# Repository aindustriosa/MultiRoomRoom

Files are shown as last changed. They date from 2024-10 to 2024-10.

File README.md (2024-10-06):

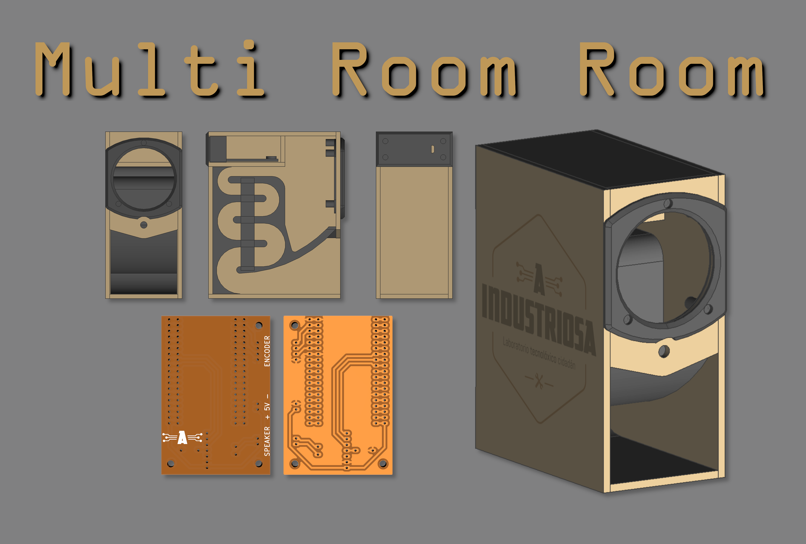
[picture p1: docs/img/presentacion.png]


Multi Room Room é un sistema de audio inalámbrico multi-habitación baseado en ESP32, Squeezelite[(1)](#1-httpsgithubcomsle118squeezelite-esp32) e Lyrion[(2)](#2-httpsgithubcomlms-communityslimserver). Permite a implementación dun sistema de fío musical inalámbrico de baixo custo e con tecnoloxías abertas. Neste repositorio atópanse as listas de materiais, deseños de placas electrónicas e caixas así como as instruccións para a posta en marcha do sistema.

## Documentación

[Documentación en galego](./docs/gl/INDICE.md)

Documentation in English (In progress)

## Referencias

#### [(1) https://github.com/sle118/squeezelite-esp32](https://github.com/sle118/squeezelite-esp32)

#### [(2) https://github.com/lms-community/slimserver](https://github.com/lms-community/slimserver)

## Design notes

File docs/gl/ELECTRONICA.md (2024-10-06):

# ESP32 + MAX98357A

Esta é a placa máis sinxela que permite implementar un altofalante dunha única canle (mono) e unha única vía (só un woofer). É a opción máis barata e compacta polo que é ideal se se queren fabricar múltiples unidades para cubrir unha estancia grande.

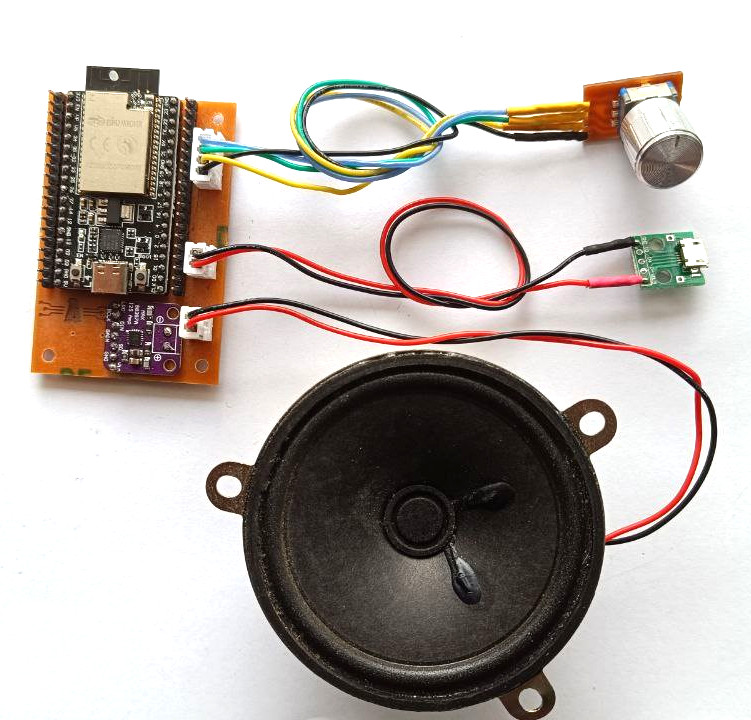
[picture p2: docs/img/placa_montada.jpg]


# Esquemático

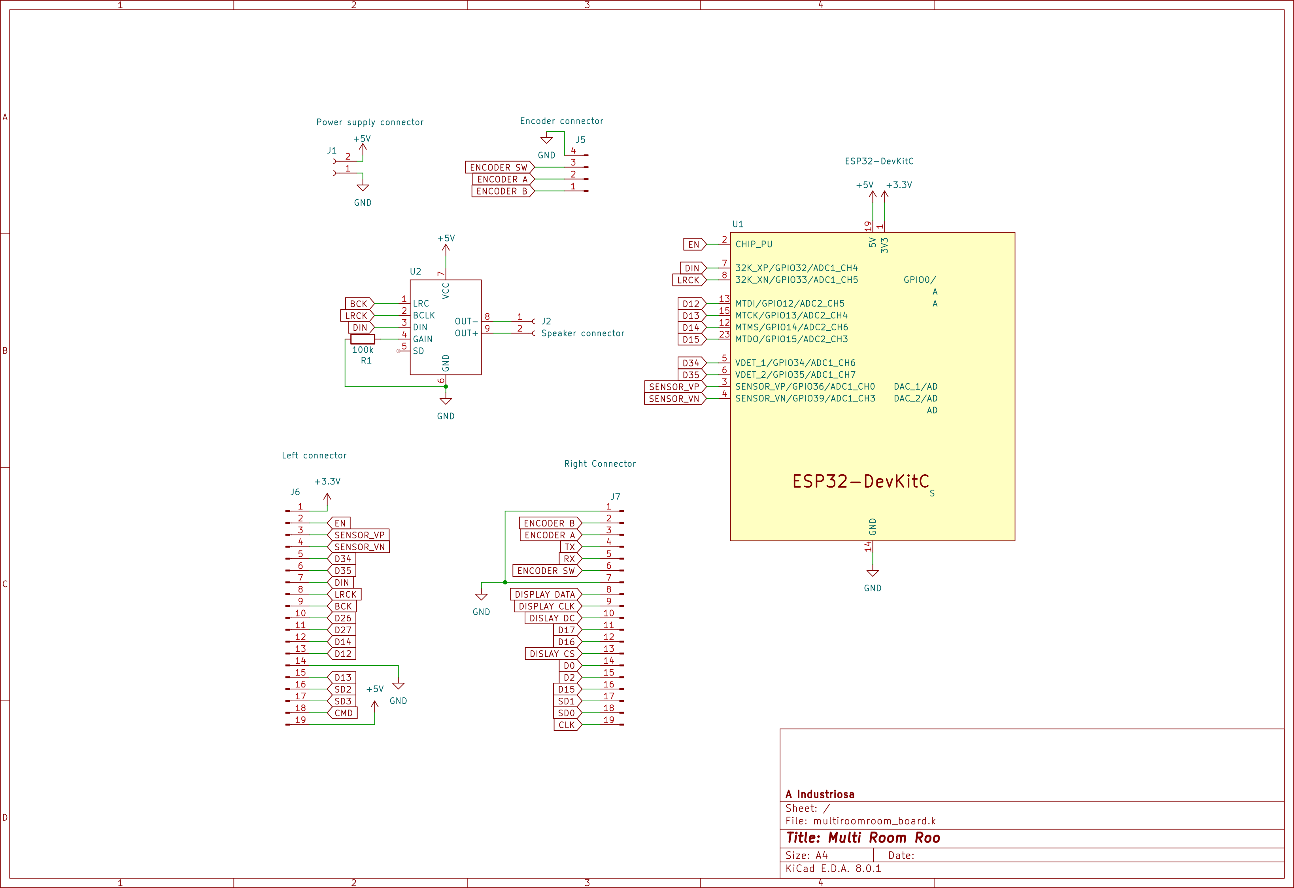
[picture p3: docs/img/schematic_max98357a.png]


# Lista de materiais

| Elemento  | Descrición | Cantidade | Imaxe |
| --- | --- | --- | --- |
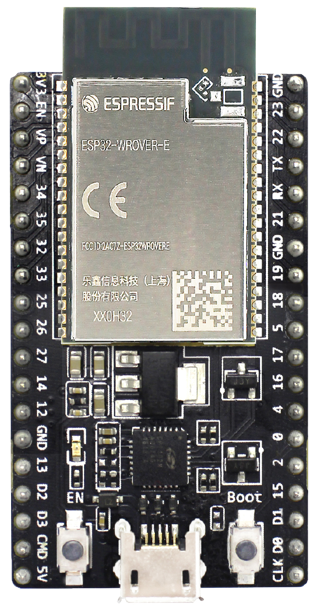
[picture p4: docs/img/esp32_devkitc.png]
| **ESP32-DevkitC con módulo WROOVER** | Microcontrolador do sistema encargado de executar o firmware Squeezelite que recibe o audio por Wifi ou Bluetooth e o envía o DAC por I2S. | 1 |  |
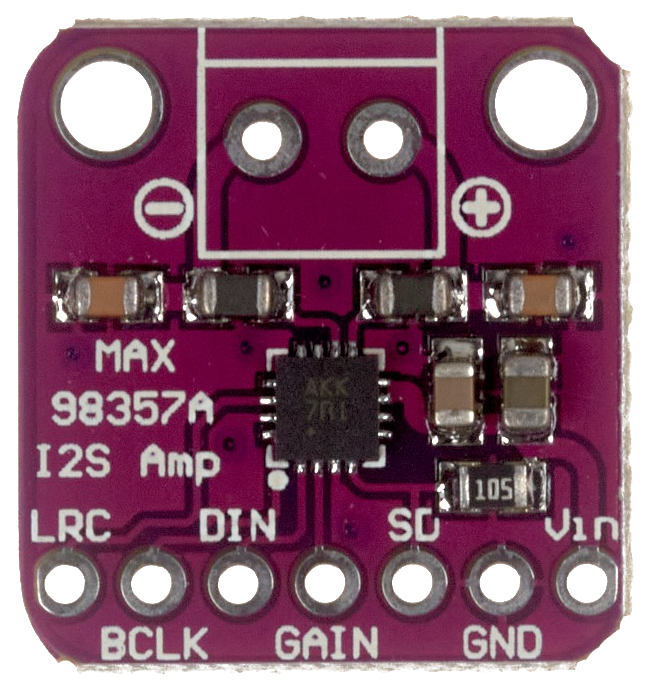
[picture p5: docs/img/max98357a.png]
| **MAX98357A DAC I2S + Amplificador 3W** | Conversor dixital a analóxico con interfaz I2S e amplificador de 3W integrado nun mesmo chip. Recibe o audio dende o ESP32 por I2S e saca un sinal analóxico que se pode alimentar directamente ó altofalante. | 1 |  |
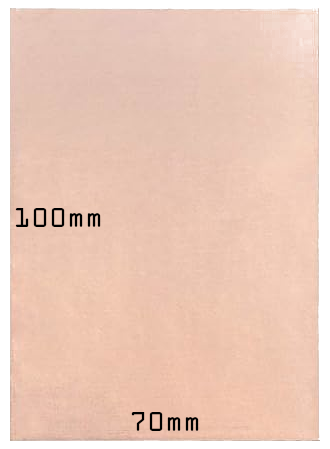
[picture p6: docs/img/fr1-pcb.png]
| **PCB FR-1 - 100x60 mm - 1 cara** | PCB de unha única cara utilizada para o mecanizado mediante CNC. Utilízase o sustrato FR-1 composto por fibras de papel debido a que durante o proceso de mecanizado se vai xerar pó do sustrato que sería altamente perigoso para a saúde se se tratase de materiais como baquelita ou fibra de vidro. | 1 |  |
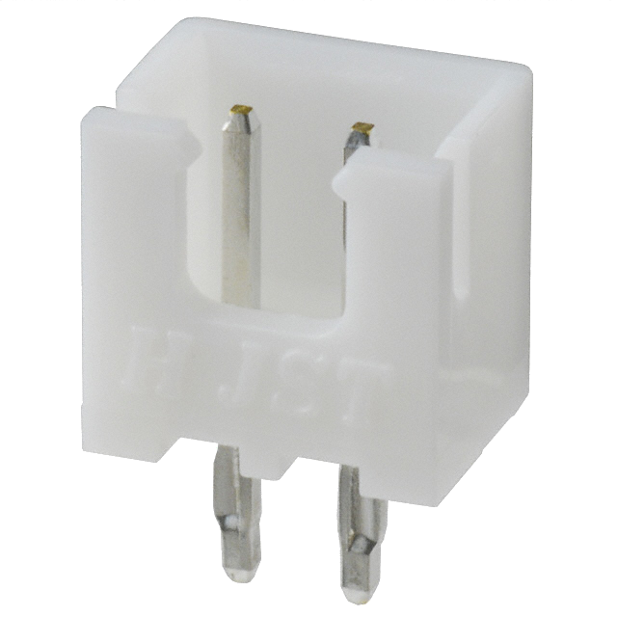
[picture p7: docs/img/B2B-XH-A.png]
| **JST B2B-XH-A** | Conector JST de 2 pins con espaciado de 2.54 mm. Un para a alimentación e outro para a conexión do woofer. | 2 |  |
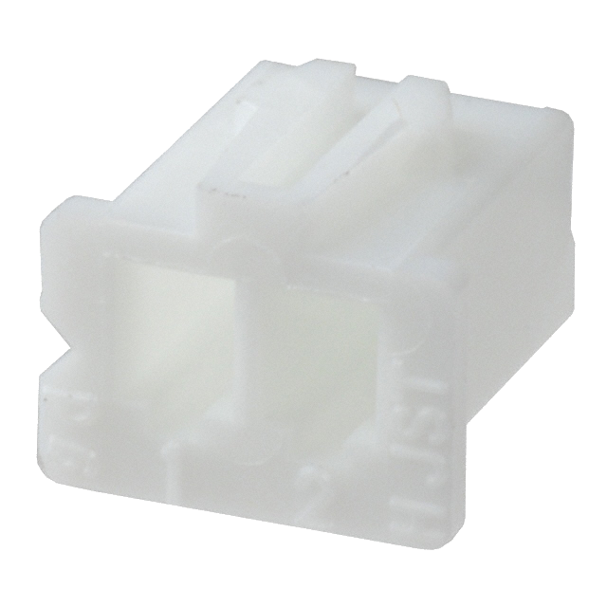
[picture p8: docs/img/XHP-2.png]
| **JST XHP-2** | Cobertura plástica para conextor JST de 2 pins e espaciado de 2.54 mm. Un para a alimentación e outro para a conexión do woofer. | 2 |  |
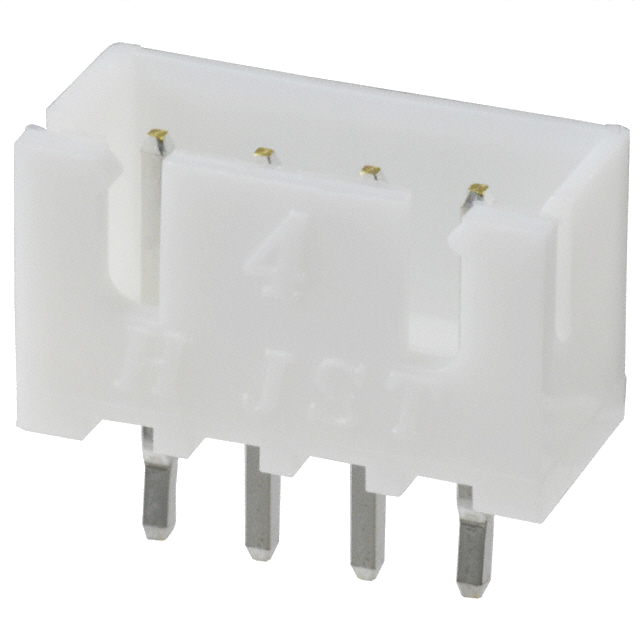
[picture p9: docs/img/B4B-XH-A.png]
| **JST B4B-XH-A** | Conector JST de 4 pins con espaciado de 2.54 mm. Para a conexión do encoder. | 1 |  |
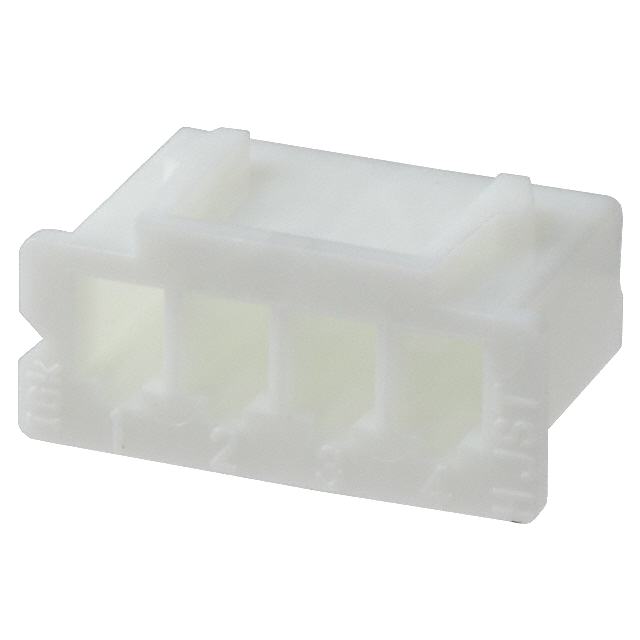
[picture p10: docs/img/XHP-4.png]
| **JST XHP-4** | Cobertura plástica para conextor JST de 4 pins e espaciado de 2.54 mm. Para a conexión do encoder. | 1 |  |
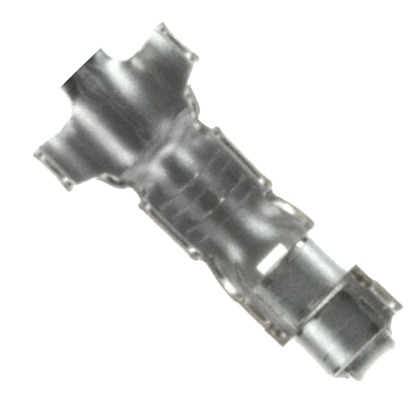
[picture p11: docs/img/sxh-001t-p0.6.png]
| **JST SXH-001T-P0.6** | Contacto metálico para crimpar. Parte dos conectores JST XH. | 8 |  |
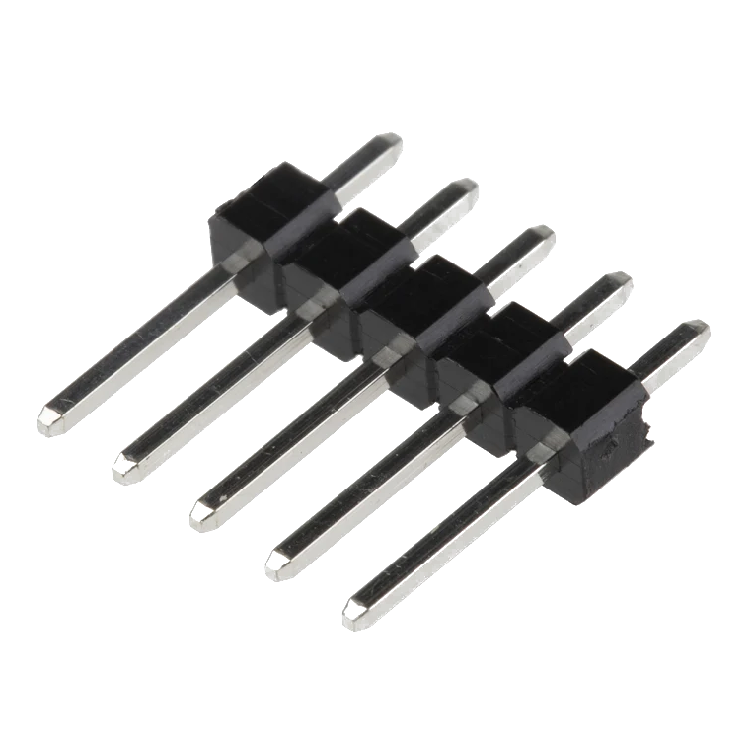
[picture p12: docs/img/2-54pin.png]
| **Cabeceiras 2.54 mm - 19 pins** | Cabeceiras de 2.54mm de espaciado para expoñer os pins do ESP32 para a conexión futura doutros periféricos. | 2 |  |
| **Cabeceiras 2.54 mm - 7 pins** | Cabeceiras de 2.54mm de espaciado para a conexión do DAC MAX98357A. | 1 |  |
| **Cabeceiras 2.54 mm - 2 pins** | Cabeceiras de 2.54mm de espaciado para a conexión do DAC MAX98357A. | 1 |  |
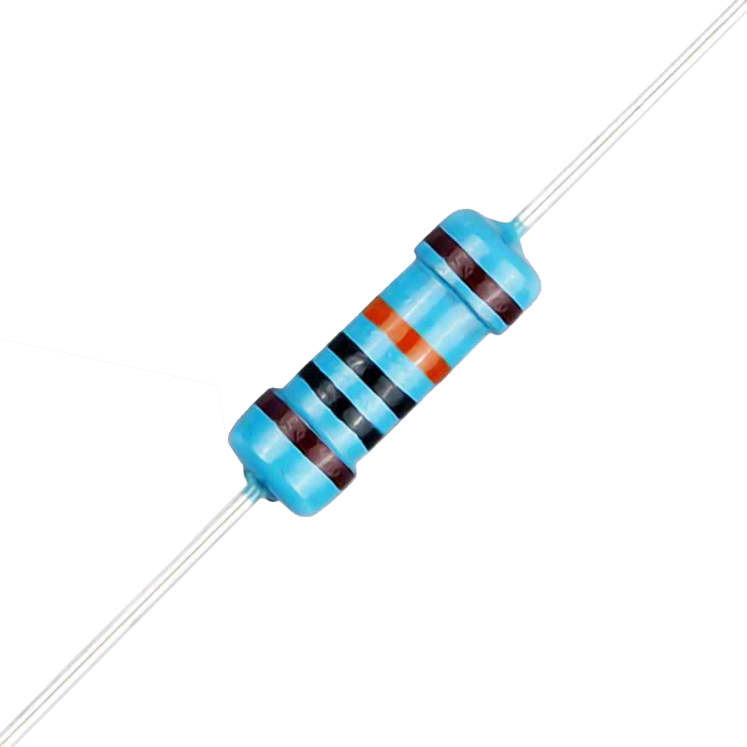
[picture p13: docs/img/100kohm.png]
| **Resistencia 100 kohm** | Resistencia de 100 Kohm para configurar a ganancia do amplificador ó valor máximo. | 1 |  |
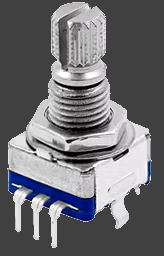
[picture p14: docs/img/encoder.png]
| **Encoder** | Encoder en cuadratura co pulsador integrado | 1 |  |
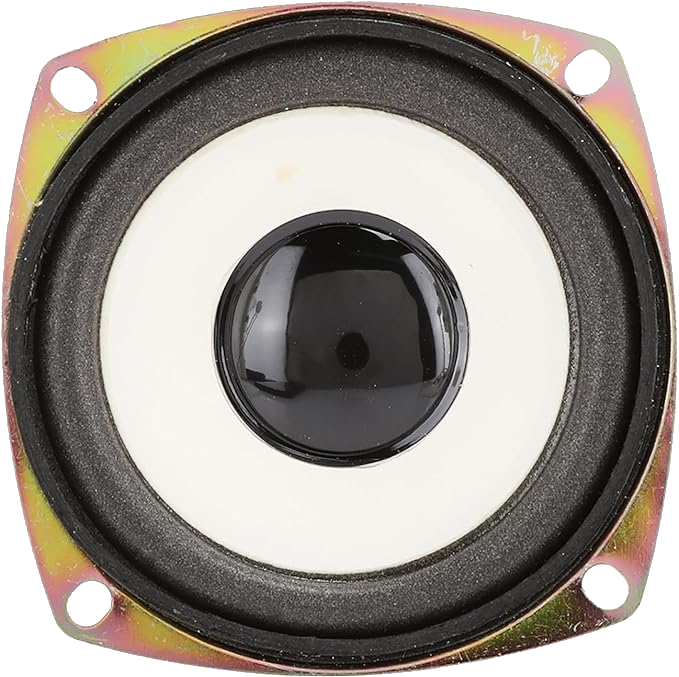
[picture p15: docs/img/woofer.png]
| **Woofer 3.3" 3W** | Altavoz de 3.3 pulgadas ou 70mm de diámetro de 4 ou 8 ohm e 3W de potencia. *Unha boa fonte para obter este tipo de woofers é a desmontaxe de antigos altofalantes de PC*. | 1 |  |
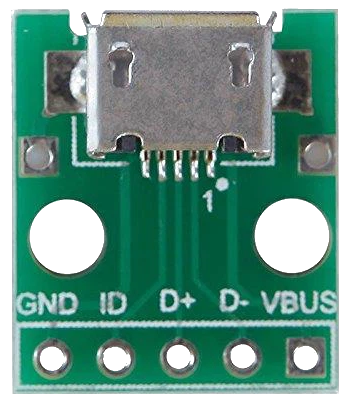
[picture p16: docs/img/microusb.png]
| **Conector micro USB con placa** | Conector micro USB empregado para a alimentacióne montado sobre unha PCB con conectores para cableado. | 1 |  |

# Fabricación mediante CNC

A PCB para a montaxe dos distintos módulos está especialmente deseñada para a súa fabricación nunha CNC (tipo 3018 ou similar). Para xerar os G-code necesarios para alimentar a máquina proponse o uso da ferramenta pcb2gcode[(1)](#1-httpsgithubcompcb2gcodepcb2gcode) que permite ler os ficheiros de fabricación (Gerber) xerados por Kicad e obter como saída os G-code para o grabado das pistas, o taladrado dos buratos e o corte da propia PCB.

Para simplificar o uso desta ferramenta recoméndase o uso da interface gráfica pcb2gcodeGUI[(2)](#2-httpsgithubcompcb2gcodepcb2gcodegui) que permite a configuración de pcb2gcode de xeito máis visual. No cartafol `hardware/pcb2gcode` atópase o ficheiro `pcb2gcodeGUI.config` que contén a configuración recomendada para o mecanizado desta PCB nunha CNC 3018 empregando unha broca de 0.4mm para o gravado e outra de 0.8mm para os taladros e o corte.

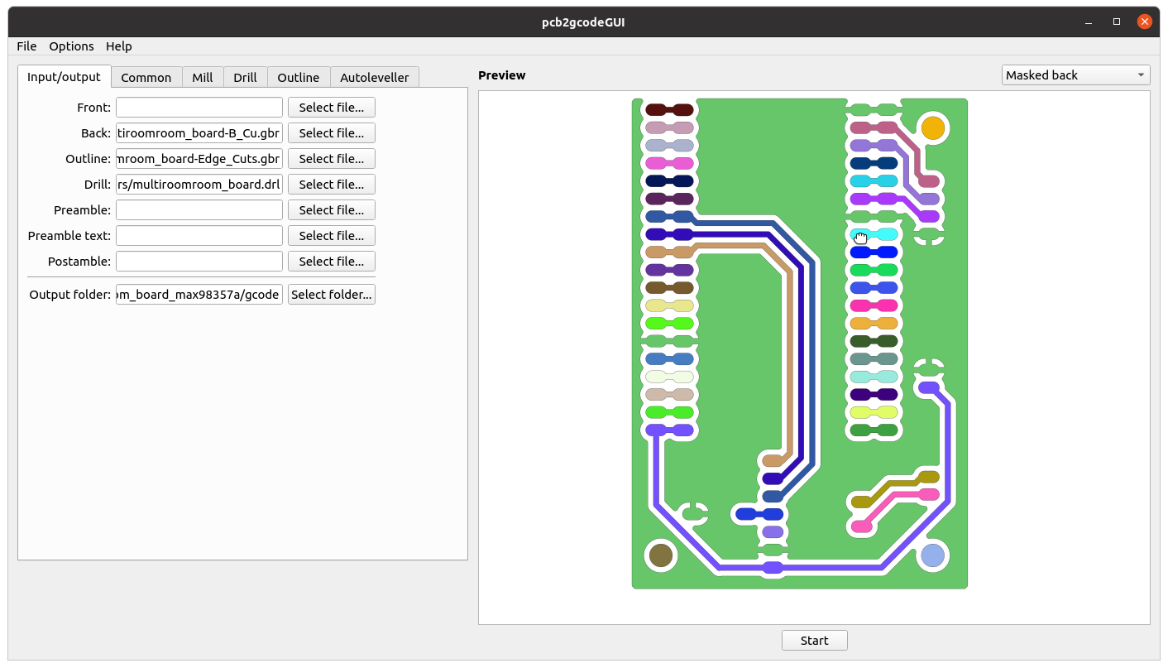
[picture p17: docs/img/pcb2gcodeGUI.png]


Seleccionar os arquivos Gerber xerados en Kicad para a fabricación colocando cada un deles na sección axeitada:

* **Back**: `hardware/multiroomroom_board_max98357a/gerbers/multiroomroom_board-B_Cu.gbr`
* **Outline**: `hardware/multiroomroom_board_max98357a/gerbers/multiroomroom_board-Edge_Cuts.gbr`
* **Drill**: `hardware/multiroomroom_board_max98357a/gerbers/multiroomroom_board.drl`
* **Output folder**: `hardware/multiroomroom_board_max98357a/gcode/`

No apartado **Common** deberase axustar o *Axis mirror offset* para que a esquina inferior esquerda da PCB quede aproximadamente na orixe de coordenadas. O valor será un pouco superior á metade do ancho da PCB a fabricar. Neste caso uns 25mm é suficiente. Isto é para evitar que o G-code xerado quede na parte negativa do eixo X o que pode dar problemas durante o mecanizado se non se ten en conta.

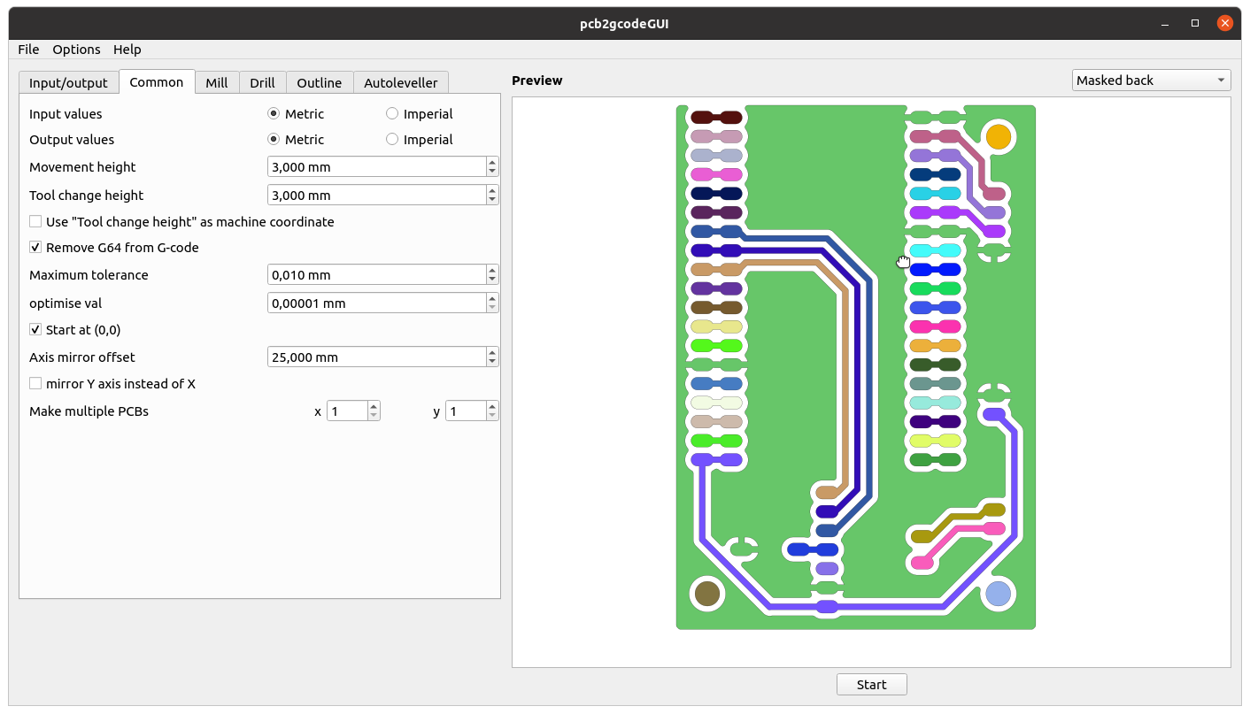
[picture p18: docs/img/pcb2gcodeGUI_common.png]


No apartado **Mill** poderase axustar a profundidade e a velocidade do gravado así como o espaciado entre pasadas. Típicamente este valor será a metade do ancho da fresa que se está empregando. Neste caso 0.2mm. Para a profundidade e a velocidade recoméndase facer probas coa maquina que se está a empregar para atopar os valores máis axeitados. 

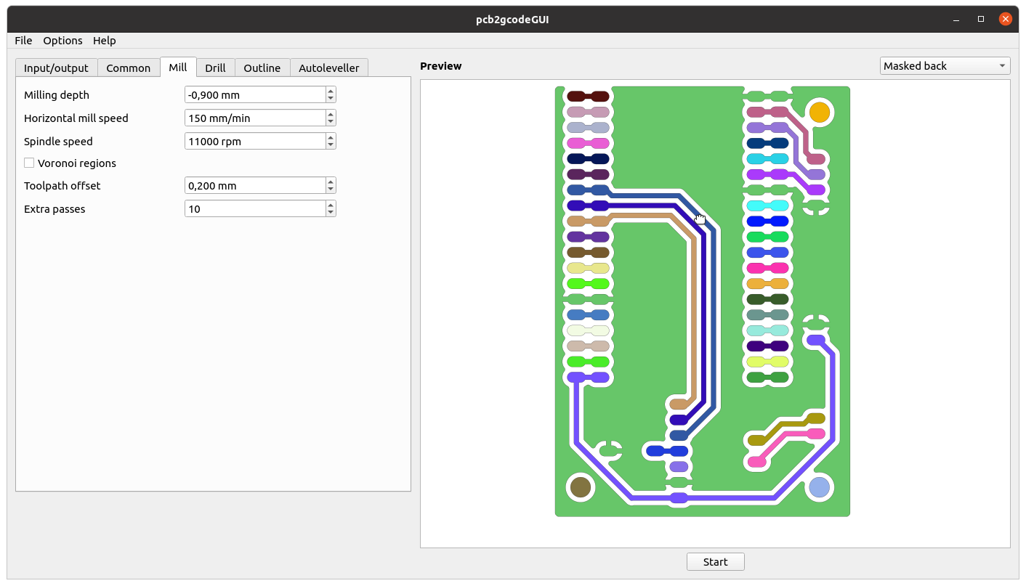
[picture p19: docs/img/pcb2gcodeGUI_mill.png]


No apartado **Drill** poderase axustar a profundidade dos buratos, que deberá ser lixeiramente superior ó grosor da PCB que se está a mecanizar. Tamén se deberá axustar a velocidade e o diámetro da fresa que se está a empregar. É necesario utilizar fresas de menos de 1mm que é o diámetro dos buratos máis pequenos da PCB.

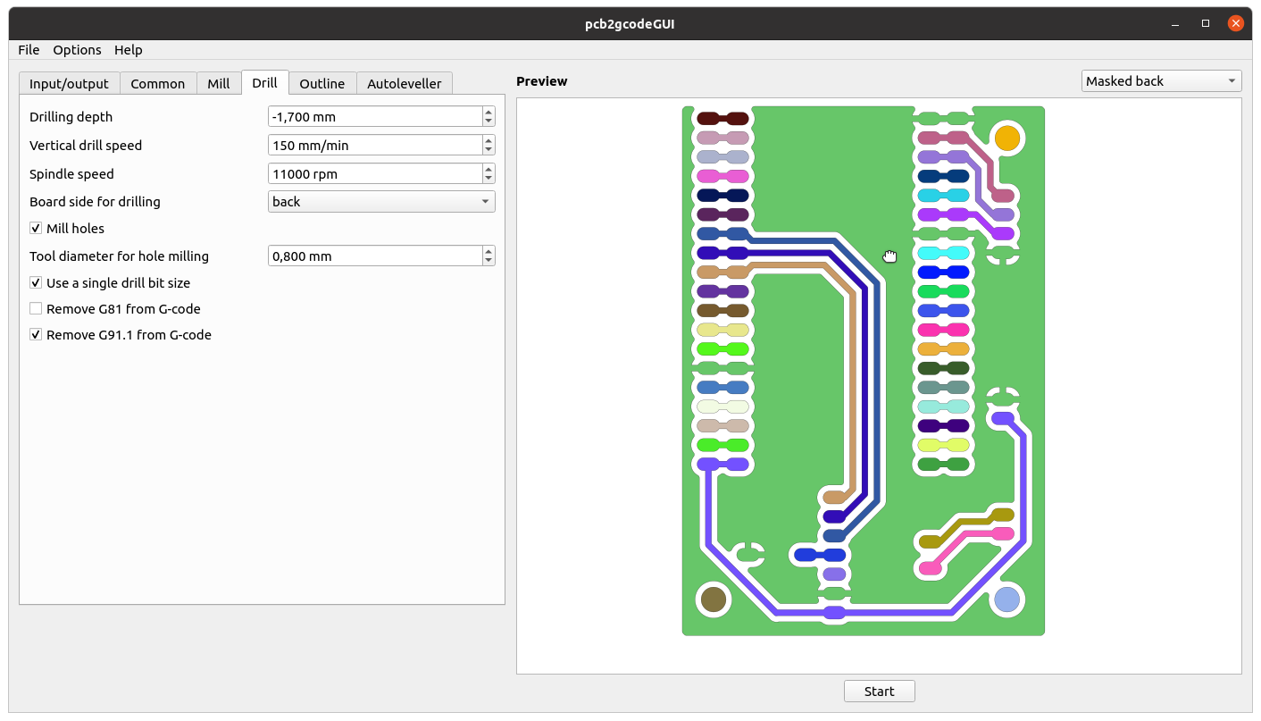
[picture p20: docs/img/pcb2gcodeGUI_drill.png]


No apartado **Outline** poderase axustar a profundidade do corte, a velocidade de movemento e a profundidade máxima de cada pasada o que determinará en cantas pasadas se fará o corte total. Tamén se poderá configurar o uso de pestañas que se deixan sen cortar entre a PCB e o material sobrante para evitar que a PCB se mova durante o corte. Empregando pestañas de 1.5mm de ancho e 0.5mm de grosor asegúrase que a PCB non se moverá e se poderá separa de xeito sinxelo do resto da placa.

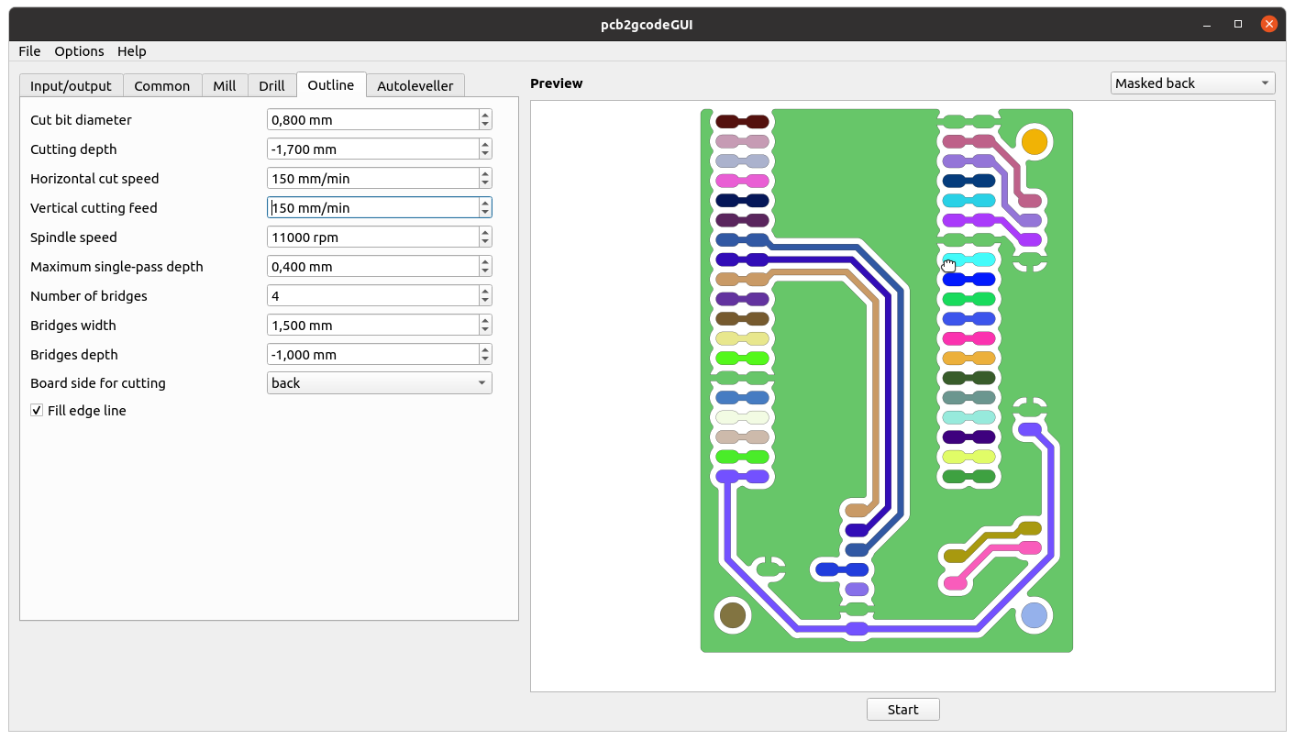
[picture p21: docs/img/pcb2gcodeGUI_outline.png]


Por último pulsando no botón **Start** o programa procesará os arquivos proporcionados e xerará os G-code necesarios para cortar a PCB. Os arquivos resultantes serán:

* **back.nc**: G-code para o gravado da cara inferior da PCB.
* **milldrill.nc**: G-code para realizar os taladros na PCB.
* **outline.nc**: G-code para realizar o corte exterior da PCB.

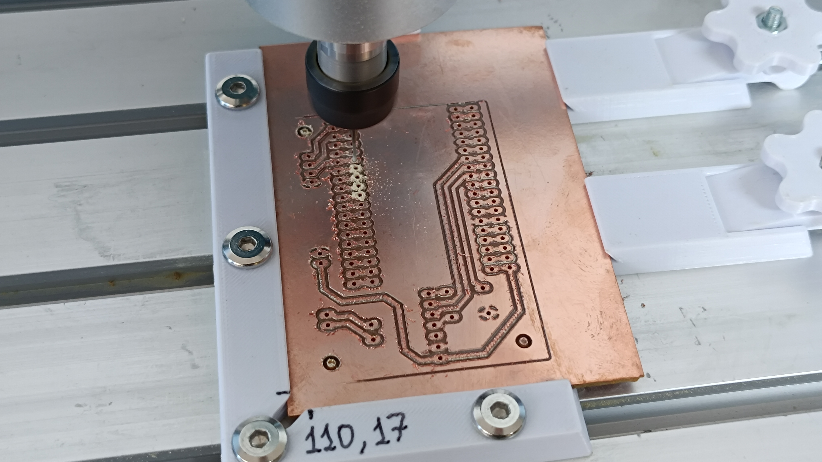
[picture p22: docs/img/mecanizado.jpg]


# Gravado da serigrafía mediante láser

TBD

# Referencias

#### [(1) https://github.com/pcb2gcode/pcb2gcode](https://github.com/pcb2gcode/pcb2gcode)
#### [(2) https://github.com/pcb2gcode/pcb2gcodeGUI](https://github.com/pcb2gcode/pcb2gcodeGUI)

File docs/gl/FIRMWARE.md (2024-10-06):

# Squeezelite ESP32

O firmware que se emprega para a recepción dos streams de audio nos altofalantes coñécese como Squeezelite-ESP32[(1)](#1-httpsgithubcomsle118squeezelite-esp32)

Squeezelite-ESP32 é un firmware para os microcontroladores ESP32 e ESP32-S3 de espressif. Ofrece as seguintes capacidades:

* Traballar como receptor de audio Bluetooth.
* Traballar como altofalante para servizos como Spotify connect ou Apple Airplay.
* Reproducción de audio de forma sincronizada utilizando o backend Lyrion (antigo Logitech Media Server).

Soporta unha grande cantidade de periféricos como:

* Botóns e encoders para distintas funcións (reproducción, pausa, pasar de canción, control de volume, etc).
* Expansores de GPIO para engadir máis botóns e LEDs.
* Receptor de infravermellos para control mediante mando a distancia (compatible con receptores de 38kHz).
* Pantallas monócromas, en escalas de grises ou a cor con conexión SPI ou I2C (compatible cos drivers SH1106, SSD1306, SSD1322, SSD1326/7, SSD1351, ST7735, ST7789 and ILI9341).
* Vúmetro con tira de LEDs WS2812B
* Conexión Ethernet compatble cos chip Microchip LAN8720 e Davicom DM9051/W5500.

Unha das funcións máis destacadas é que inclúe unha completa interface web para a configuración de todos os parámetros do dispositivo.

# Instalador de binarios precompilados

Para a instalación do firmware é posible utilizar o instalador web proporcionado en [https://sle118.github.io/squeezelite-esp32-installer/](https://sle118.github.io/squeezelite-esp32-installer/) o que permite instalar firmwares precompilados de xeito moi sinxelo.

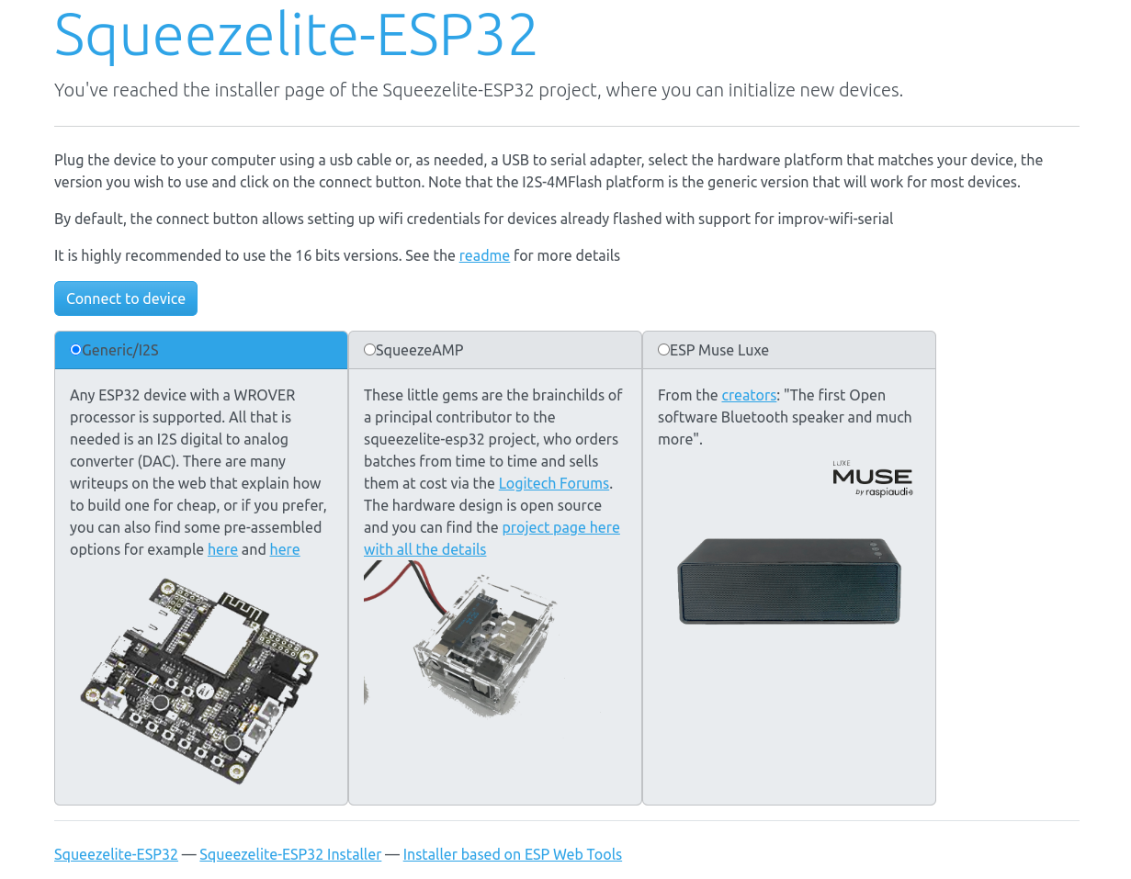
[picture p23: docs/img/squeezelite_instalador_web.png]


A continuación conectar o ESP32-DevkitC Wroover cun cable USB-C ó PC e na interface web seleccionar a opción **Generic/I2S** e pulsar o botón **Connect to device**. No desplegable escoller o dispositivo USB que corresponda ó ESP (normalmente será un dispositovo CP2102) e pulsar en **Connect**.

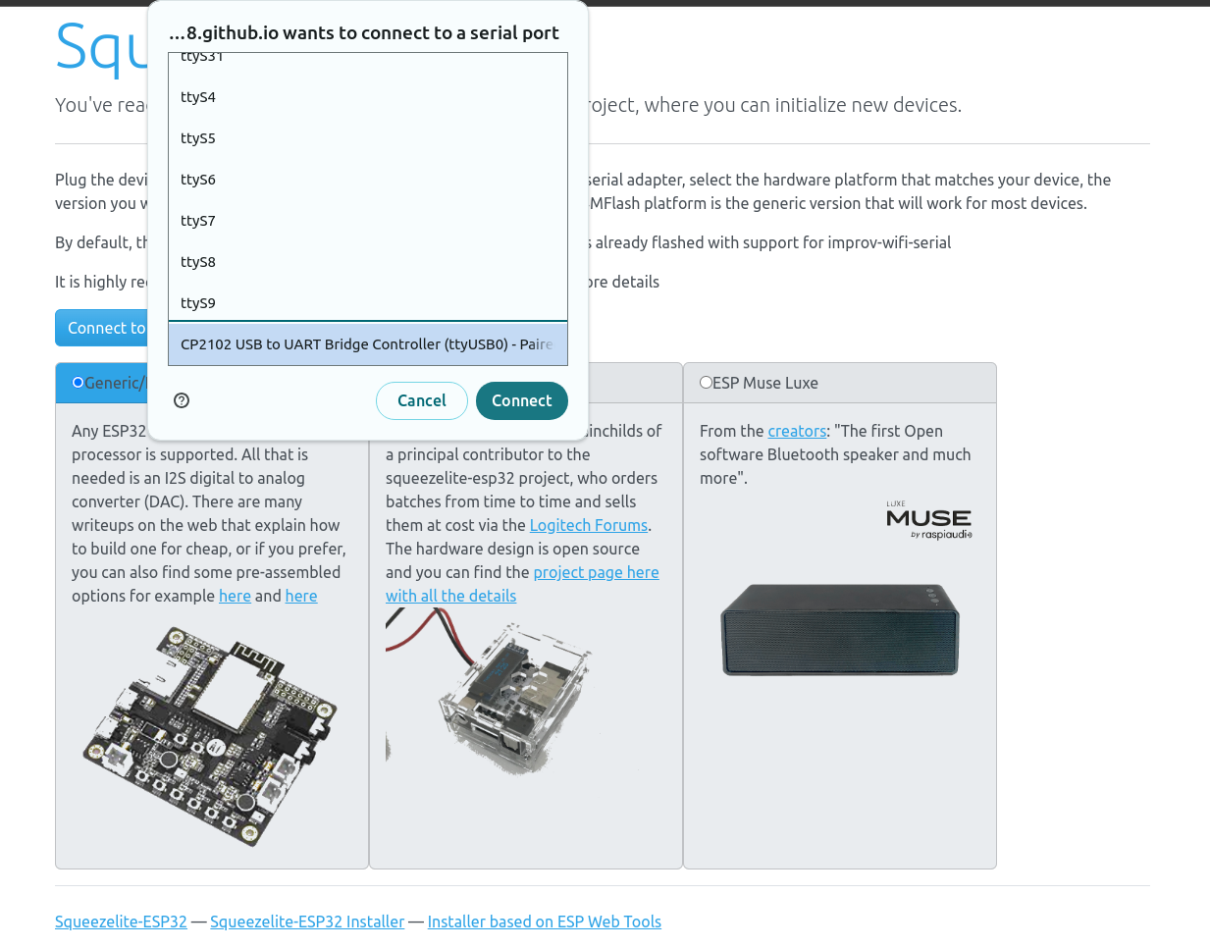
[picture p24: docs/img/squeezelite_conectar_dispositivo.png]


Escoller a opción **Install I2S-4MFLASH-16**

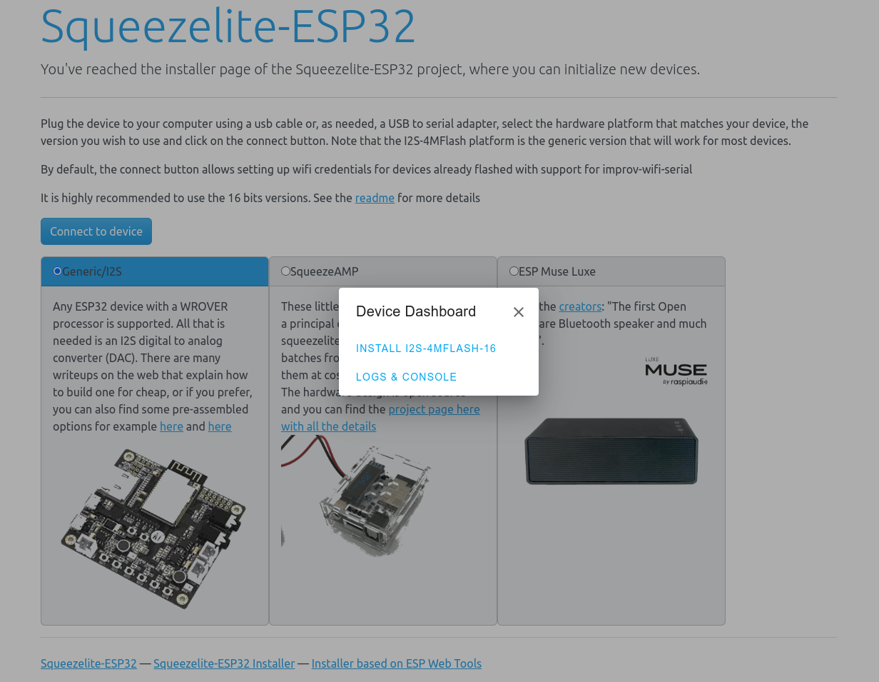
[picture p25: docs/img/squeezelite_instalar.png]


Marcar a opción **Erase device** e pulsar en **Next**



Pulsar en **Install**



Agardar que remate o proceso de instalación



# Compilación e instalación

TBD

# Configuración

En canto o ESP32 teña instlado o firmwarae e se reinicie, aparecerá unha nova rede wifi co nome **squeezelite-identificador**. Deberase conectar o PC a esta rede introducindo o contrasinal **squeezelite**. Accedendo entón á dirección http://192.168.4.1 mostrase a interface web de configuración de Squeezelite.

O primeiro paso é conectar o dispositivo a unha rede wifi. Para iso no apartado **Wifi** pulsar o botón **Scan** se a rede ainda non aparece entre as detectadas. Unha vez que apareza seleccionala e introducir o contrasinal. Cando o dispositivo se conecte á rede aparecerá unha pequena fiestra indicando a nova IP do dispositivo dentro da rede Wifi á que se conectou.



Entrando na nova IP volverase recargar a interface web e poderase continuar coa configuración do dispositivo. A continuación cargarase o ficheiro de configuración por defecto para a placa ESP32 + MAX98357A. Para iso ir á sección **NVS Editor** e na parte inferior pulsar no botón **Load File**, seleccionar o archivo `software/multiroomroom_max98357a/nvs_multiroomroom_max98357a.json`



No editor amosaranse entón todos os cambios que se aplicarán co novo ficheiro cargado.



Recomendamos editar todos os campos nos que apareza o nome **multiroomroom1** para darlle ó dispositivo un nome axeitado. Tamén recomendamos modificar o cambpo **ap_pwd**. Este campo establece o contrasinal da rede wifi que o dispositivo pon en marcha a modo de recpueración ante a impsibilidade de conectar á rede wifi que se configurou previamente. Por último pulsar o botón **Commit** e **Exit Recovery** na parte inferior da pantalla.

Neste punto o dispositivo xa está listo para a súa conexión a un servidor Lyrion ou para recibir audio de Spotify Connect ou actuar como altofalante Bluetooth. A Desfrutar!!!

# Referencias

* #### [(1) https://github.com/sle118/squeezelite-esp32](https://github.com/sle118/squeezelite-esp32)

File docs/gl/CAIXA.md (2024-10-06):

# Caixa tipo "back loaded horn"

Deseño de caixa tipo *back loaded horn* baseado no deseño de **@guppyk** en thingiverse [(1)](#1-httpswwwthingiversecomthing4668173).

Esta caixa está pensada para replicar o deseño de **@guppyk** pero adaptándoo para poder facer a maior parte da caixa de madeira empregando corte láser. O resto de partes mantéñense en impresión 3D.



# Corte láser

O deseño está pensado para que se poida cortar nun taboleiro de **400x400x5mm**. Recoméndase o uso de DM ou contrachapado para este tipo de proxectos xa que ten mellores propiedades acústicas que a madeira natural Para isto pódese empregar o aquivo `hardware/simple_box/laser_cut.svg`



## Dimensions das pezas de madeira

### Frontal



### Superior e traseira (2 pezas iguais)



### Inferior



### Laterais (2 pezas iguais)



### Compartimento para a electrónica (peza traseira)



### Compartimento para a electrónica (peza inferior)



# Pezas impresas en 3D

Este tipo de caixas emprega unha canle en forma de guía de ondas cuxa sección se vai incrementando a medida que se afasta da fonte de son. Deste xeito a cancle contribúe a amplificar as frecuencias máis graves incrementando a súa presencia e mellorando así a respoista de woofers de pequeno tamaño que presamente teñen respostas bastante pobres neste rango.

No deseño orixinal todo o corpo da caixa do altofalante se fabrica en impresión 3D mentres que só os paneis laterais se fan en madeira. Nesta versión preténdese reducir o uso de impresión 3D por dúas razóns: por unha parte a madeira ten mellores propiedades acústicas que o plastica e por outra parte o corte mediante láser acelera de forma considerable o proceso de fabricación fronte á impresión 3D.

> **Todas as pezas están deseñadas para ser impresas sen utilizar soportes**

### Canle

O arquivo a imprimir é `hardware/caixa/canle.3mf`





### Tapa traseira

A tapa traseira fai de soporte para a electrónica que se monta dentro da caixa ó tempo que proporciona unha parede traseira na que expoñer calquera conector que sexa necesario para o dispositivo. Neste caso únicamente se inclúe un conector micro USB para a alimentación pero poderíase de forma moi sinxela sustituir por ou engadir calquera outro tipo de conector que fose necesario.

O arquivo a imprimir é `hardware/caixa/tapa_traseira.3mf`





### Soportes para insertos

Xa que a madeira que se emprega é de 5mm de grosor non é posible a inserción de parafusos directamente na madeira. Para todas aquelas pezas que poidan requererir a súa desmontaxe deseñaronse soportes que van encolados na madeira e permiten o uso de insertos roscados nos que poden apertar os parafusos.

#### Soporte insertos woofer

O arquivo a imprimir é `hardware/caixa/soporte_insertos_woofer.3mf`



#### Soporte insertos tapa traseira (2 pezas)

O arquivo a imprimir é `hardware/caixa/canle.3mf`



# Referencias

#### [[1] https://www.thingiverse.com/thing:4668173](https://www.thingiverse.com/thing:4668173)

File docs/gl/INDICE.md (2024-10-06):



Multi Room Room é un sistema de audio multi habitación baseado no software [Lyrion](https://lyrion.org/), antigamente coñecido como Logitech Media Server. Este software componse dun servidor multimedia central que sen encarga do envío de fluxos de audio a dispositivos reproductores conectados na mesma rede local. Estes reproductores, coñecidos como _Squeeze Boxes_ poden funcionar de forma inalámbrica permitindo construir un sistema de fío musical onde os reproductores emitan o son de xeito sincronizado.

O obxectivo deste proxecto é conseguir un sistema de audio multi habitación inalámbrico de baixo custe e completamente aberto tanto en hardware como en software. 

* ### [Electrónica](./ELECTRONICA.md)
* ### [Firmware](./FIRMWARE.md)
* ### [Caixa](./CAIXA.md)

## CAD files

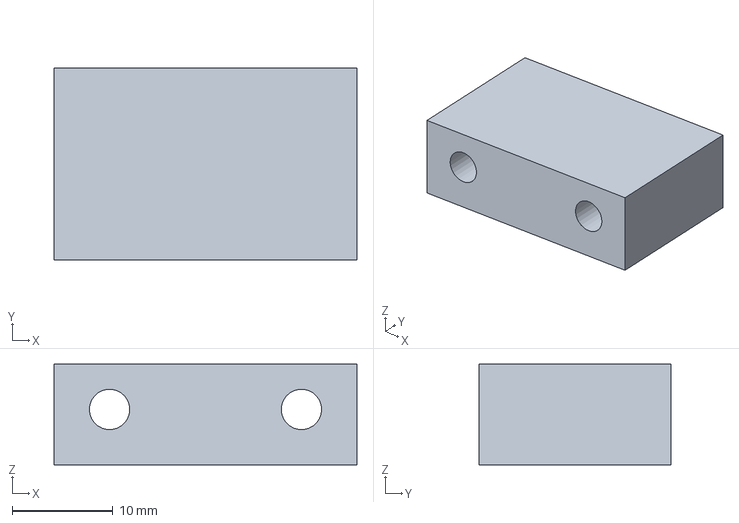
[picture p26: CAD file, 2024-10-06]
hardware/caixa/soporte_insertos_tapa_traseira.3mf
30.0 x 19.0 x 10.0 mm

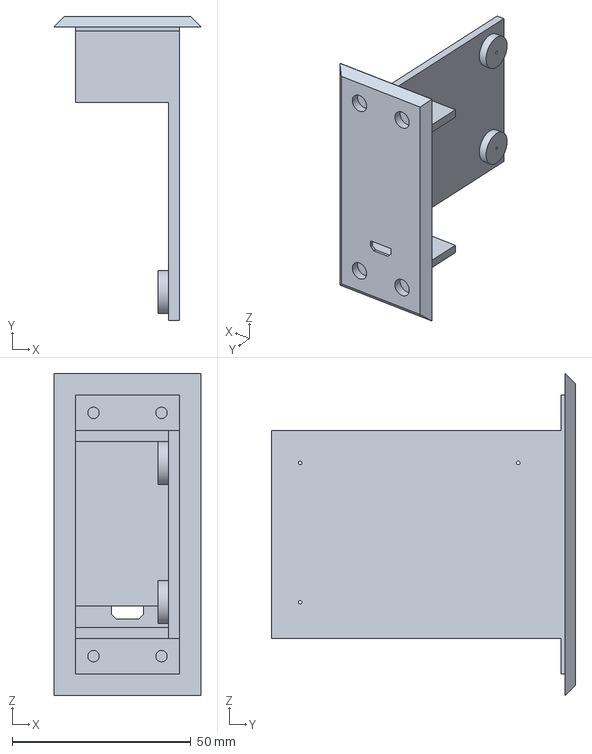
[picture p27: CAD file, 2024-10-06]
hardware/caixa/tapa_traseira.3mf
41.0 x 85.0 x 90.0 mm

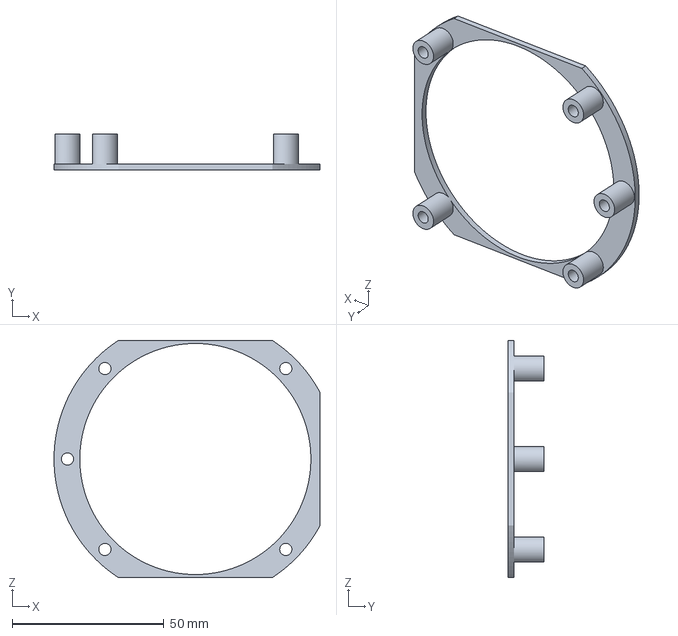
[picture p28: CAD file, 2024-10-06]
hardware/caixa/soporte_insertos_woofer.3mf
87.5 x 12.0 x 78.0 mm

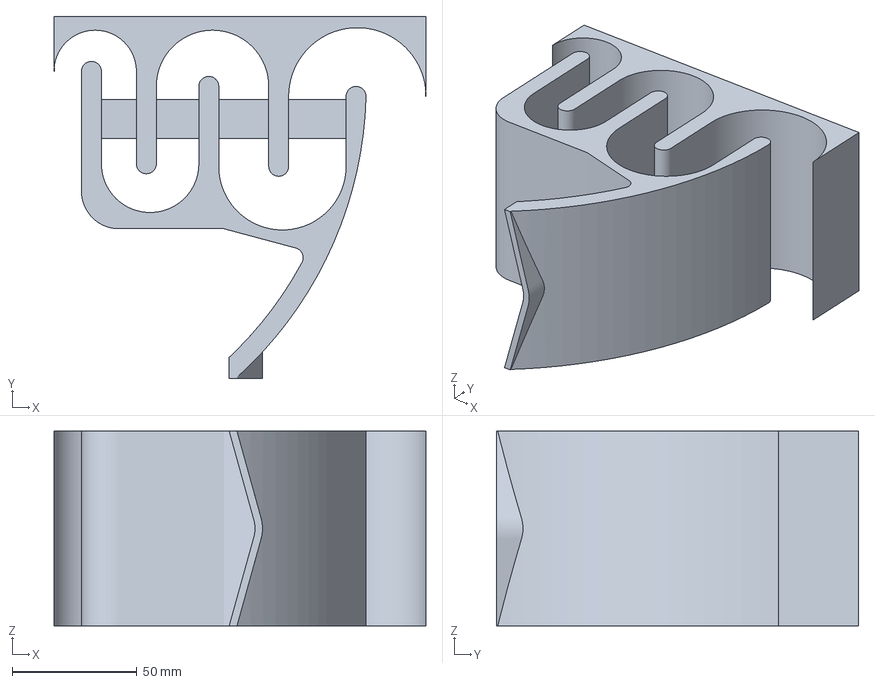
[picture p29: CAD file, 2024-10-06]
hardware/caixa/canle.3mf
149.0 x 145.0 x 78.0 mm

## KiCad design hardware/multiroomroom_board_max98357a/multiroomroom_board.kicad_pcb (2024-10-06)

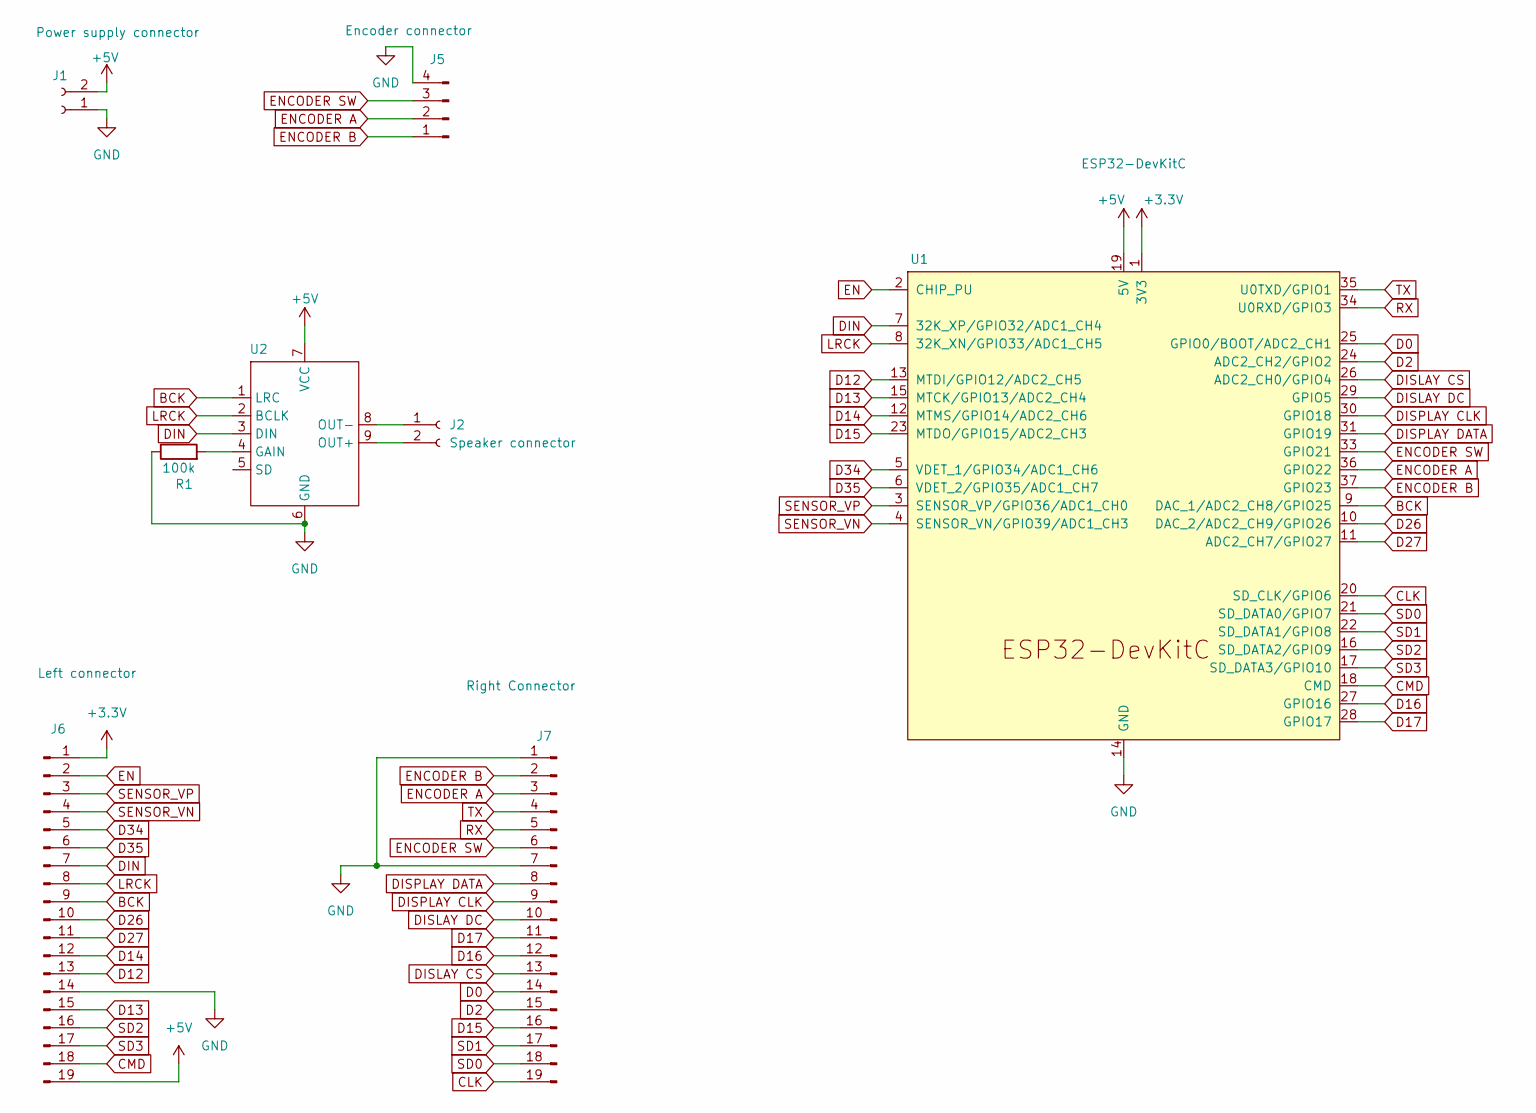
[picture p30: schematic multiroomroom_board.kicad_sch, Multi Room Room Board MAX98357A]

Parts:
J1: Power supply connector; JST_XH_B2B-XH-A_1x02_P2.50mm_Vertical
J2: Speaker connector; JST_XH_B2B-XH-A_1x02_P2.50mm_Vertical
J5: Encoder connector; JST_XH_B4B-XH-A_1x04_P2.50mm_Vertical
J6: Left connector; PinHeader_1x19_P2.54mm_Vertical
J7: Right Connector; PinHeader_1x19_P2.54mm_Vertical
R1: 100k; R_Axial_DIN0207_L6.3mm_D2.5mm_P7.62mm_Horizontal
U1: ESP32-DevKitC
U2: MAX98357A

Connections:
+3.3V: J6.1, U1.1 (3V3)
+5V: J1.2, J6.19, U1.19 (5V), U2.7 (VCC)
BCK: J6.9, U1.9 (DAC_1/ADC2_CH8/GPIO25), U2.1 (LRC)
CLK: J7.19, U1.20 (SD_CLK/GPIO6)
CMD: J6.18, U1.18 (CMD)
D0: J7.14, U1.25 (GPIO0/BOOT/ADC2_CH1)
D2: J7.15, U1.24 (ADC2_CH2/GPIO2)
D12: J6.13, U1.13 (MTDI/GPIO12/ADC2_CH5)
D13: J6.15, U1.15 (MTCK/GPIO13/ADC2_CH4)
D14: J6.12, U1.12 (MTMS/GPIO14/ADC2_CH6)
D15: J7.16, U1.23 (MTDO/GPIO15/ADC2_CH3)
D16: J7.12, U1.27 (GPIO16)
D17: J7.11, U1.28 (GPIO17)
D26: J6.10, U1.10 (DAC_2/ADC2_CH9/GPIO26)
D27: J6.11, U1.11 (ADC2_CH7/GPIO27)
D34: J6.5, U1.5 (VDET_1/GPIO34/ADC1_CH6)
D35: J6.6, U1.6 (VDET_2/GPIO35/ADC1_CH7)
DIN: J6.7, U1.7 (32K_XP/GPIO32/ADC1_CH4), U2.3 (DIN)
DISLAY CS: J7.13, U1.26 (ADC2_CH0/GPIO4)
DISLAY DC: J7.10, U1.29 (GPIO5)
DISPLAY CLK: J7.9, U1.30 (GPIO18)
DISPLAY DATA: J7.8, U1.31 (GPIO19)
EN: J6.2, U1.2 (CHIP_PU)
ENCODER A: J5.2, J7.3, U1.36 (GPIO22)
ENCODER B: J5.1, J7.2, U1.37 (GPIO23)
ENCODER SW: J5.3, J7.6, U1.33 (GPIO21)
GND: J1.1, J5.4, J6.14, J7.1, J7.7, R1.1, U1.14 (GND), U1.32 (GND), U1.38 (GND), U2.6 (GND)
LRCK: J6.8, U1.8 (32K_XN/GPIO33/ADC1_CH5), U2.2 (BCLK)
unnamed: J2.1, U2.8 (OUT-)
unnamed: J2.2, U2.9 (OUT+)
unnamed: R1.2, U2.4 (GAIN)
RX: J7.5, U1.34 (U0RXD/GPIO3)
SD0: J7.18, U1.21 (SD_DATA0/GPIO7)
SD1: J7.17, U1.22 (SD_DATA1/GPIO8)
SD2: J6.16, U1.16 (SD_DATA2/GPIO9)
SD3: J6.17, U1.17 (SD_DATA3/GPIO10)
SENSOR_VN: J6.4, U1.4 (SENSOR_VN/GPIO39/ADC1_CH3)
SENSOR_VP: J6.3, U1.3 (SENSOR_VP/GPIO36/ADC1_CH0)
TX: J7.4, U1.35 (U0TXD/GPIO1)

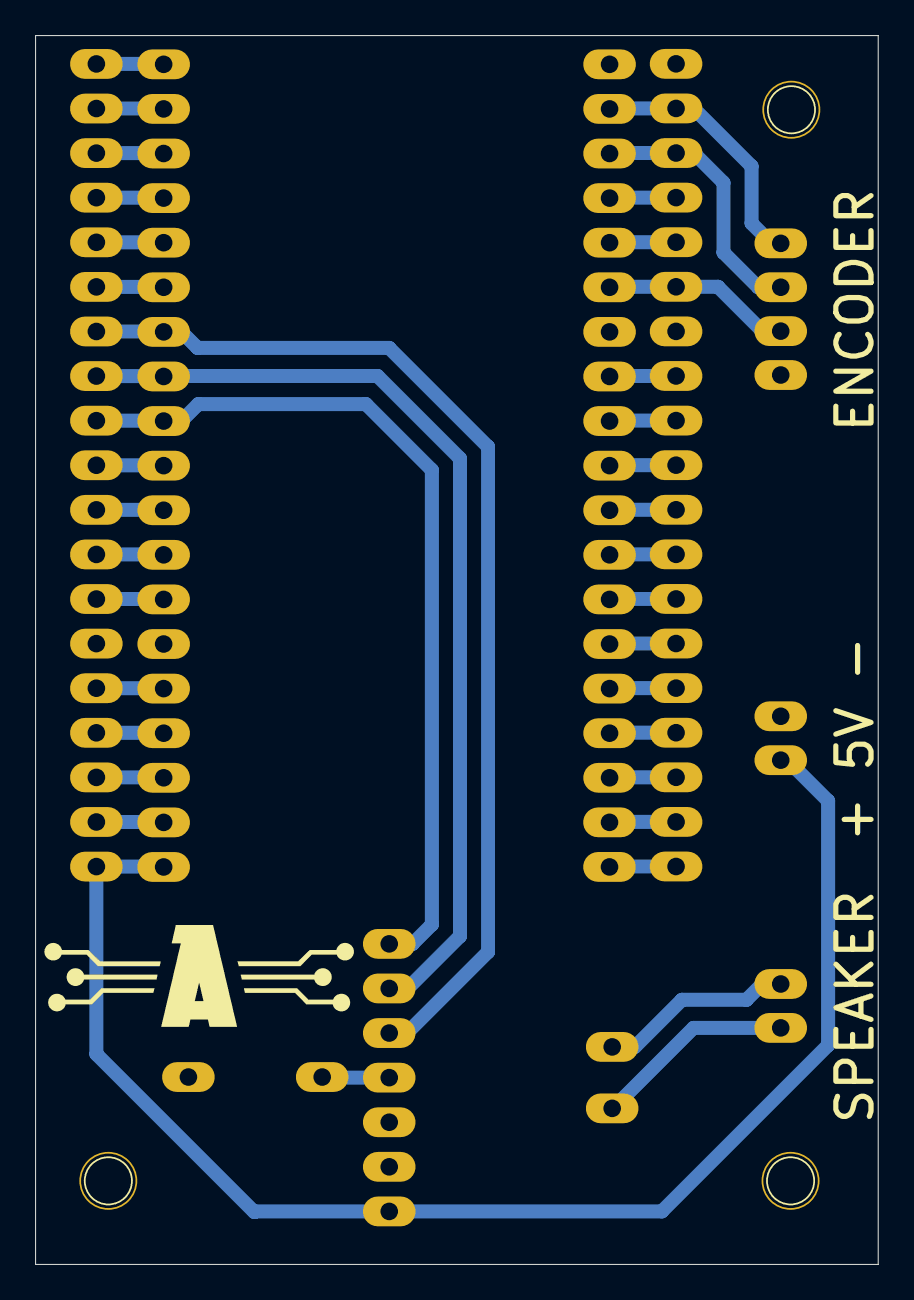
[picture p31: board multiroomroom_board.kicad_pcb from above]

Board: 2 copper layers, 48.0 x 70.0 mm, 8 parts (0 on the bottom side), 39 nets.

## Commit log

2024-10-06 How to flash firmware
    [multiroomroom_board.kicad_sch]
2024-10-06 Speaker box docs
    [canle.3mf, soporte_insertos_tapa_traseira.3mf, soporte_insertos_woofer.3mf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]
